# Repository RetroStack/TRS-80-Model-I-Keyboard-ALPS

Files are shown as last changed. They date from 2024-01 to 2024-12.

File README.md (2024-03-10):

# TRS-80 Model 1 - ALPS Keyboard Replica PCB

This project is a faithful reimplementation of the ALPS keyboard PCB of the iconic TRS-80 Model 1 computer. My revision, the E1, is designed to replicate the PCB design 1-to-1 of the original down to the traces. The entire project is available under the MIT license.

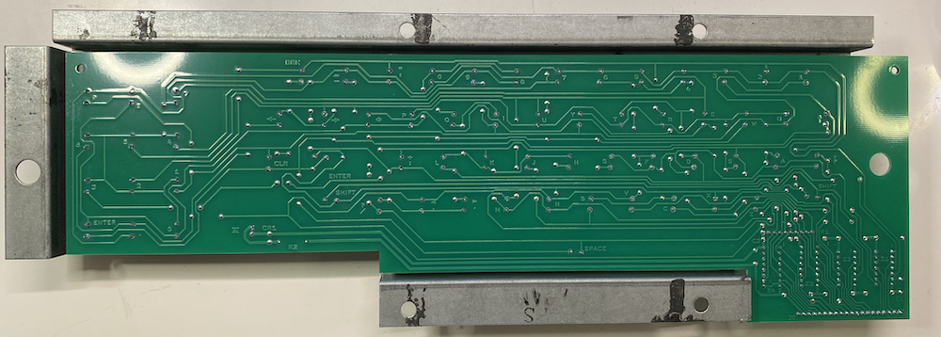
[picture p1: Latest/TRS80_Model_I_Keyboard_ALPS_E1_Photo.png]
E1 Replica


## Project Details

### Latest Files

In the "Latest" folder, you'll find the most up-to-date design files, including:

- Gerber files suitable for popular online PCB manufacturers like [PCBWay](/Latest/TRS80_Model_I_Keyboard_ALPS_E1_Gerber_PCBWay.zip) and [JLCPCB](/Latest/TRS80_Model_I_Keyboard_ALPS_E1_Gerber_JLCPCB.zip). Most manufacturers should be fine with either.
- A Bill of Materials (BOM) in [PDF](/Latest/TRS80_Model_I_Keyboard_ALPS_E1_BOM.pdf) format.
- The [full schematics](/Latest/TRS80_Model_I_Keyboard_ALPS_E1_Schematics.pdf) of the E1 replica which is 1:1 to the original G board.

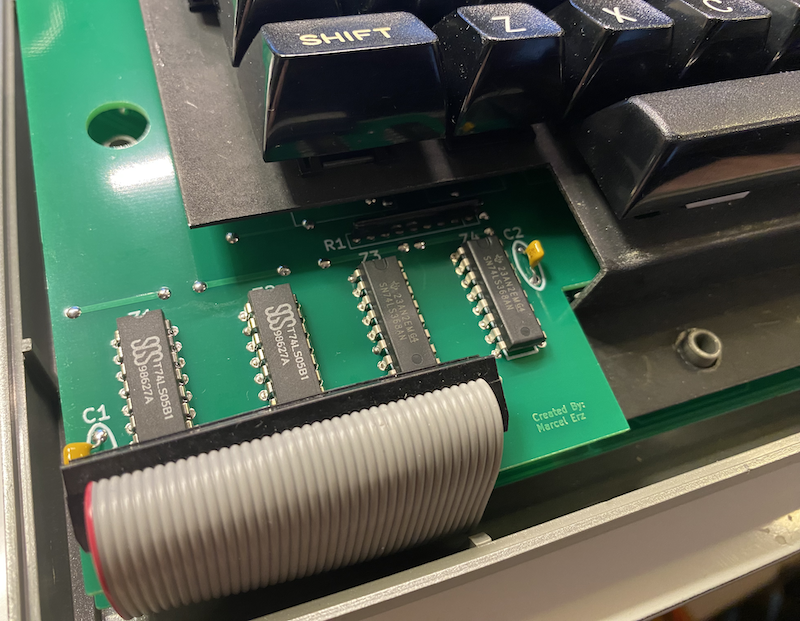
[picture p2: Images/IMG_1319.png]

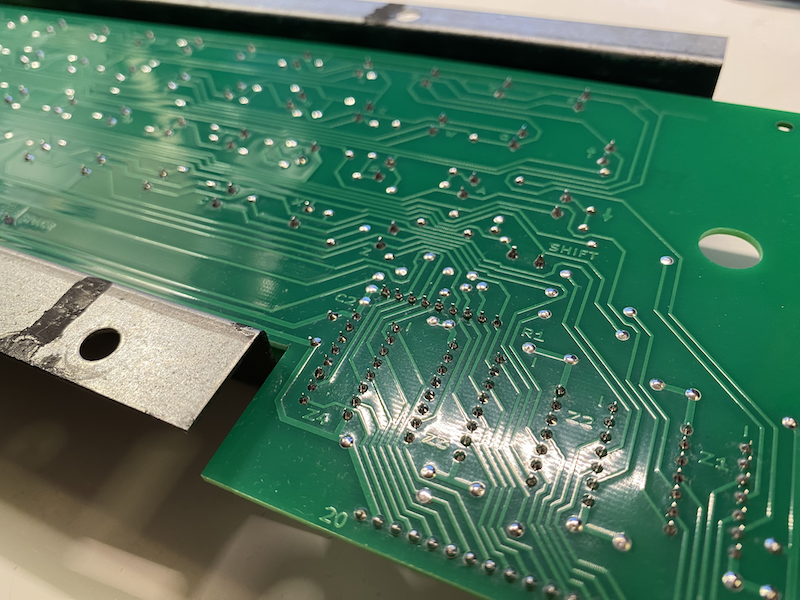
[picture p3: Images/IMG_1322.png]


### Implementation

E1 has been implemented using KiCAD 7. The KiCAD project files are included in this repository.

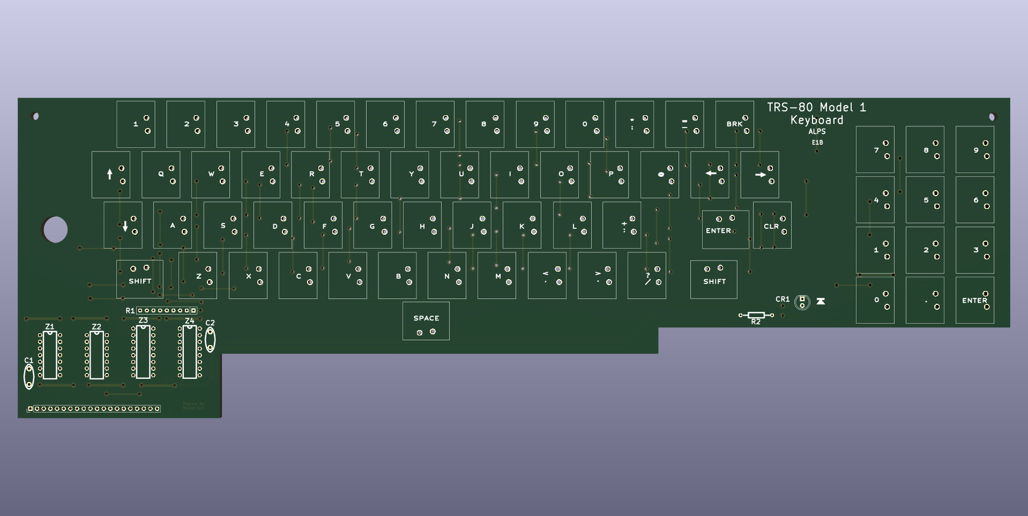
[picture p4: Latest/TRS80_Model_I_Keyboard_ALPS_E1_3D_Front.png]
E1 Replica Front

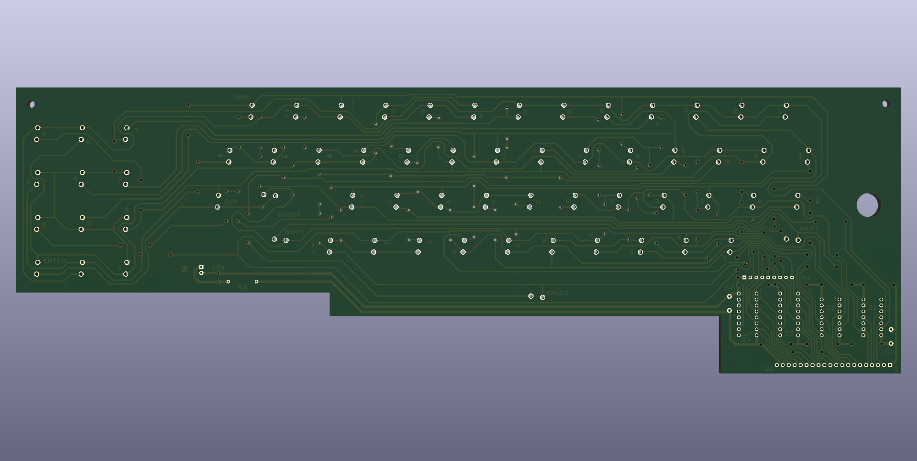
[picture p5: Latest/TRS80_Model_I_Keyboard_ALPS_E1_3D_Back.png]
E1 Replica Back


### RetroStack Libraries

To work with this KiCAD project, you'll need the RetroStack libraries for KiCAD. Please [follow this link](https://www.github.com/RetroStack/KiCAD-Libraries) to access and install these libraries.

## Main TRS-80 Model 1 Repository

For additional resources related to the TRS-80 Model 1, be sure to check out the [central page for the TRS-80 Model 1](https://www.github.com/RetroStack/TRS-80-Model-I) on [RetroStack](https://www.github.com/RetroStack).

## Support this Project

RetroStack is passionate about exploring and preserving the legacy of older computer systems. My work involves creating detailed documentation and videos to share the knowledge. I am also dedicated to reviving these classic systems by reimplementing them and offering replacement parts at no cost. If you're keen on supporting this unique project, I invite you to visit my [Patreon page](https://www.patreon.com/RetroStack). Your support would be immensely valuable and greatly appreciated!

## License

This project is licensed under the MIT License - see the [LICENSE](LICENSE) file for details.

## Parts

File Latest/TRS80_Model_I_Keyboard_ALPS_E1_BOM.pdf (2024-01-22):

### TRS-80 Model 1 ALPS Keyboard BOM

Ref | Qnty | Value | Cmp name | Footprint | Description
C1, C2 | 2 | 0.1uF | C | RetroStackLibrary:TRS80_Model_I_C_Disc_9.5L_4W_6P_Small | Unpolarized capacitor
CR1 | 1 | RED 5mm | LED | LED_THT:LED_D5.0mm | Light emitting diode
J1 | 1 | Connector | Conn_01x20 | Connector_PinHeader_2.54mm:PinHeader_1x20_P2.54mm_Vertical | Generic connector, single row, 01x20
R1 | 1 | 4.7k | R_Network08_Split | Resistor_THT:R_Array_SIP9 | 8 resistor network, star topology, bussed resistors, split
R2 | 1 | 330 | R | RetroStackLibrary:TRS80_Model_I_R_0.25W | Resistor
SW1-SW65 | 1 | @ | SW_Push | Button_Switch_Keyboard:SW_Matias_1.00u | Push button switch, generic, two pins
Z1, Z2 | 2 | 74LS05 | 74LS05 | RetroStackLibrary:TRS80_Model_I_DIP14 | Inverter Open Collect
Z3, Z4 | 2 | 74LS368 | 74LS368_Split | RetroStackLibrary:TRS80_Model_I_DIP16 | Hex buffer 3-State outputs

1

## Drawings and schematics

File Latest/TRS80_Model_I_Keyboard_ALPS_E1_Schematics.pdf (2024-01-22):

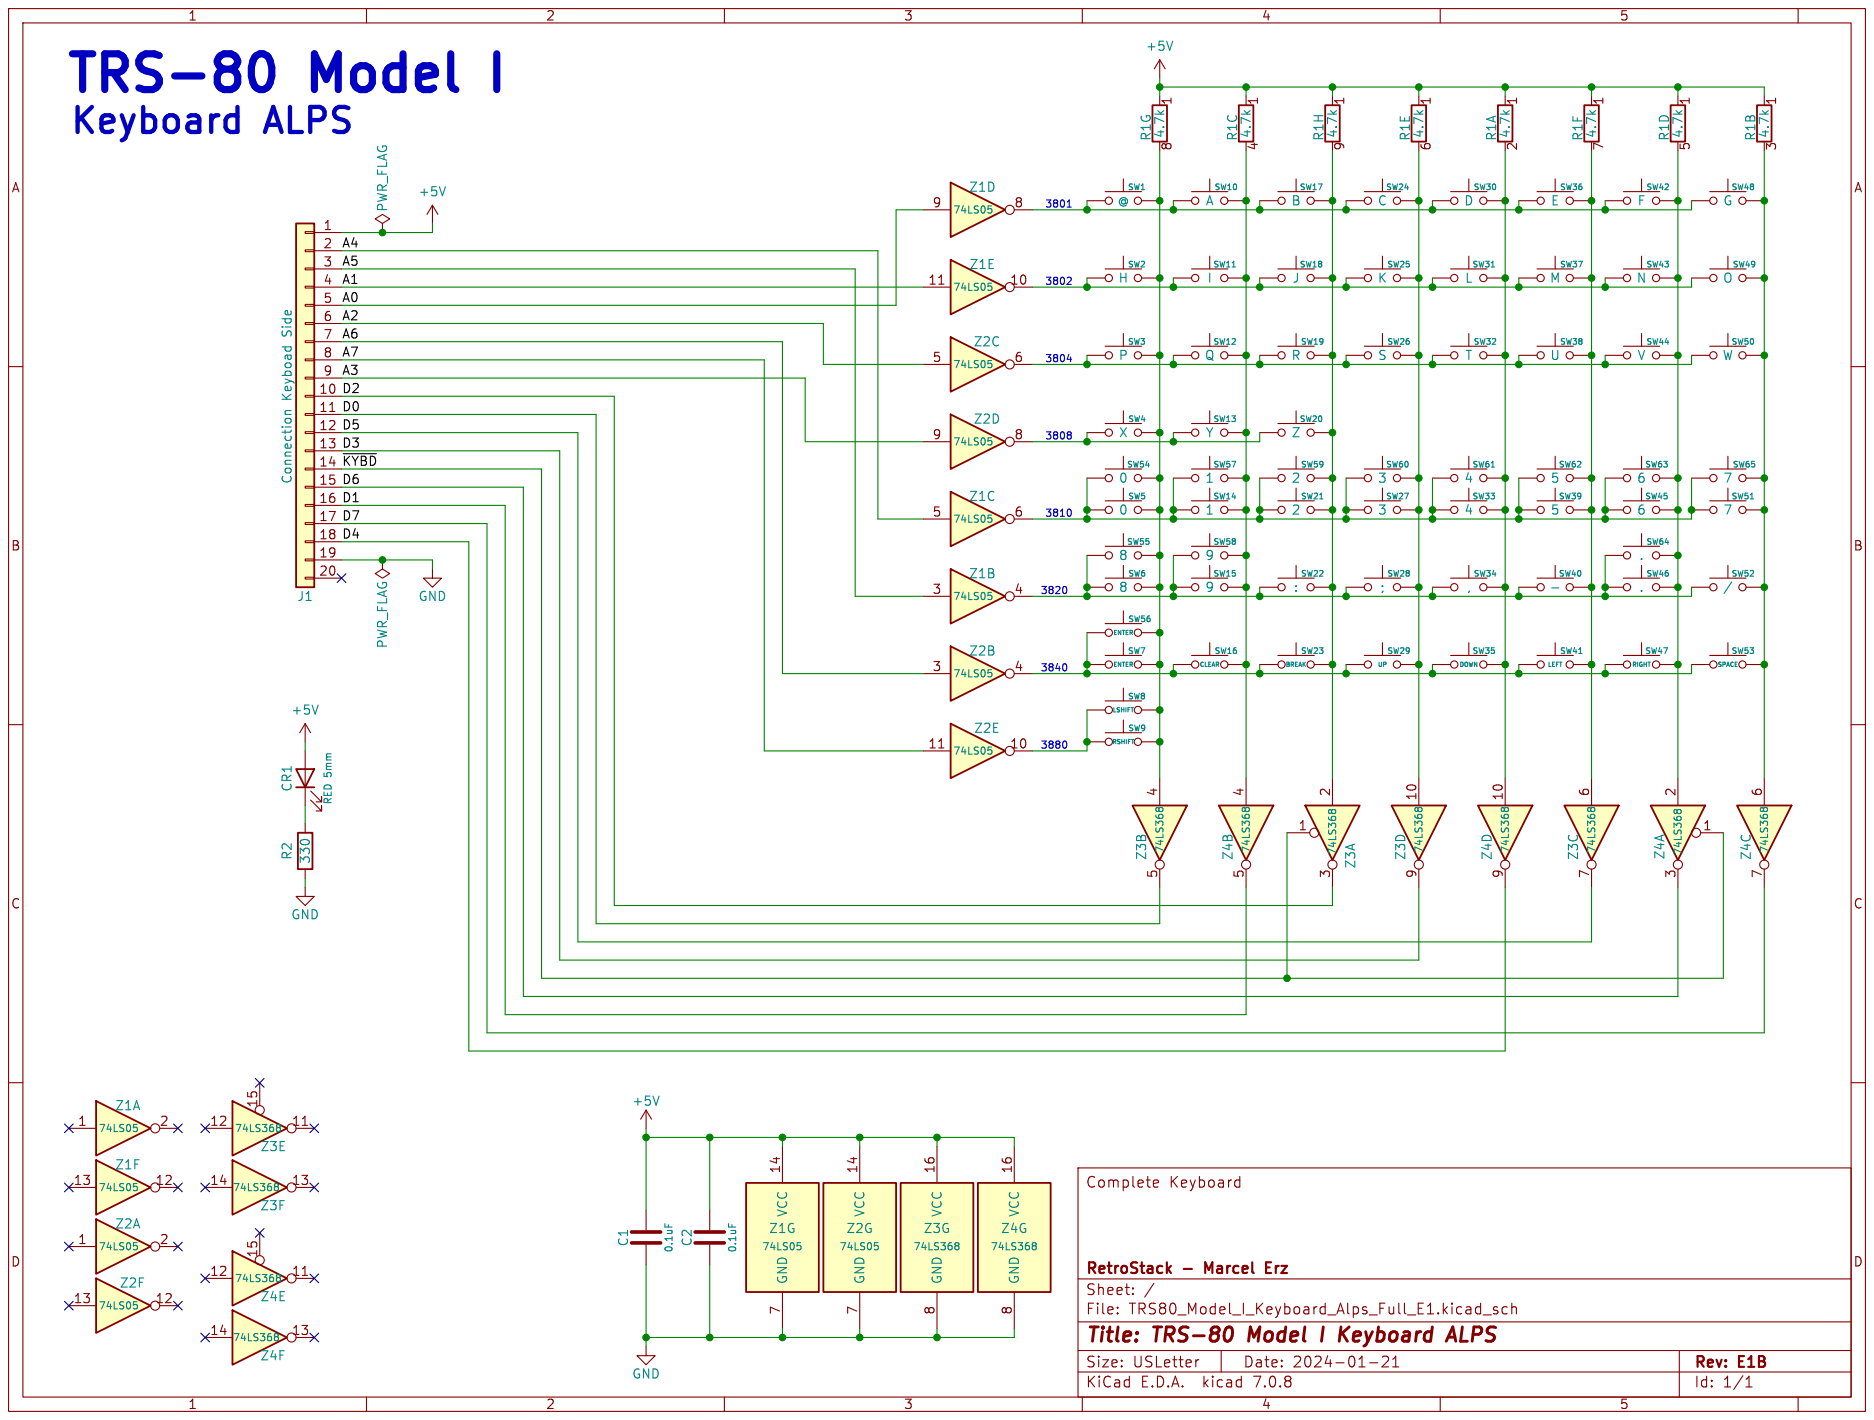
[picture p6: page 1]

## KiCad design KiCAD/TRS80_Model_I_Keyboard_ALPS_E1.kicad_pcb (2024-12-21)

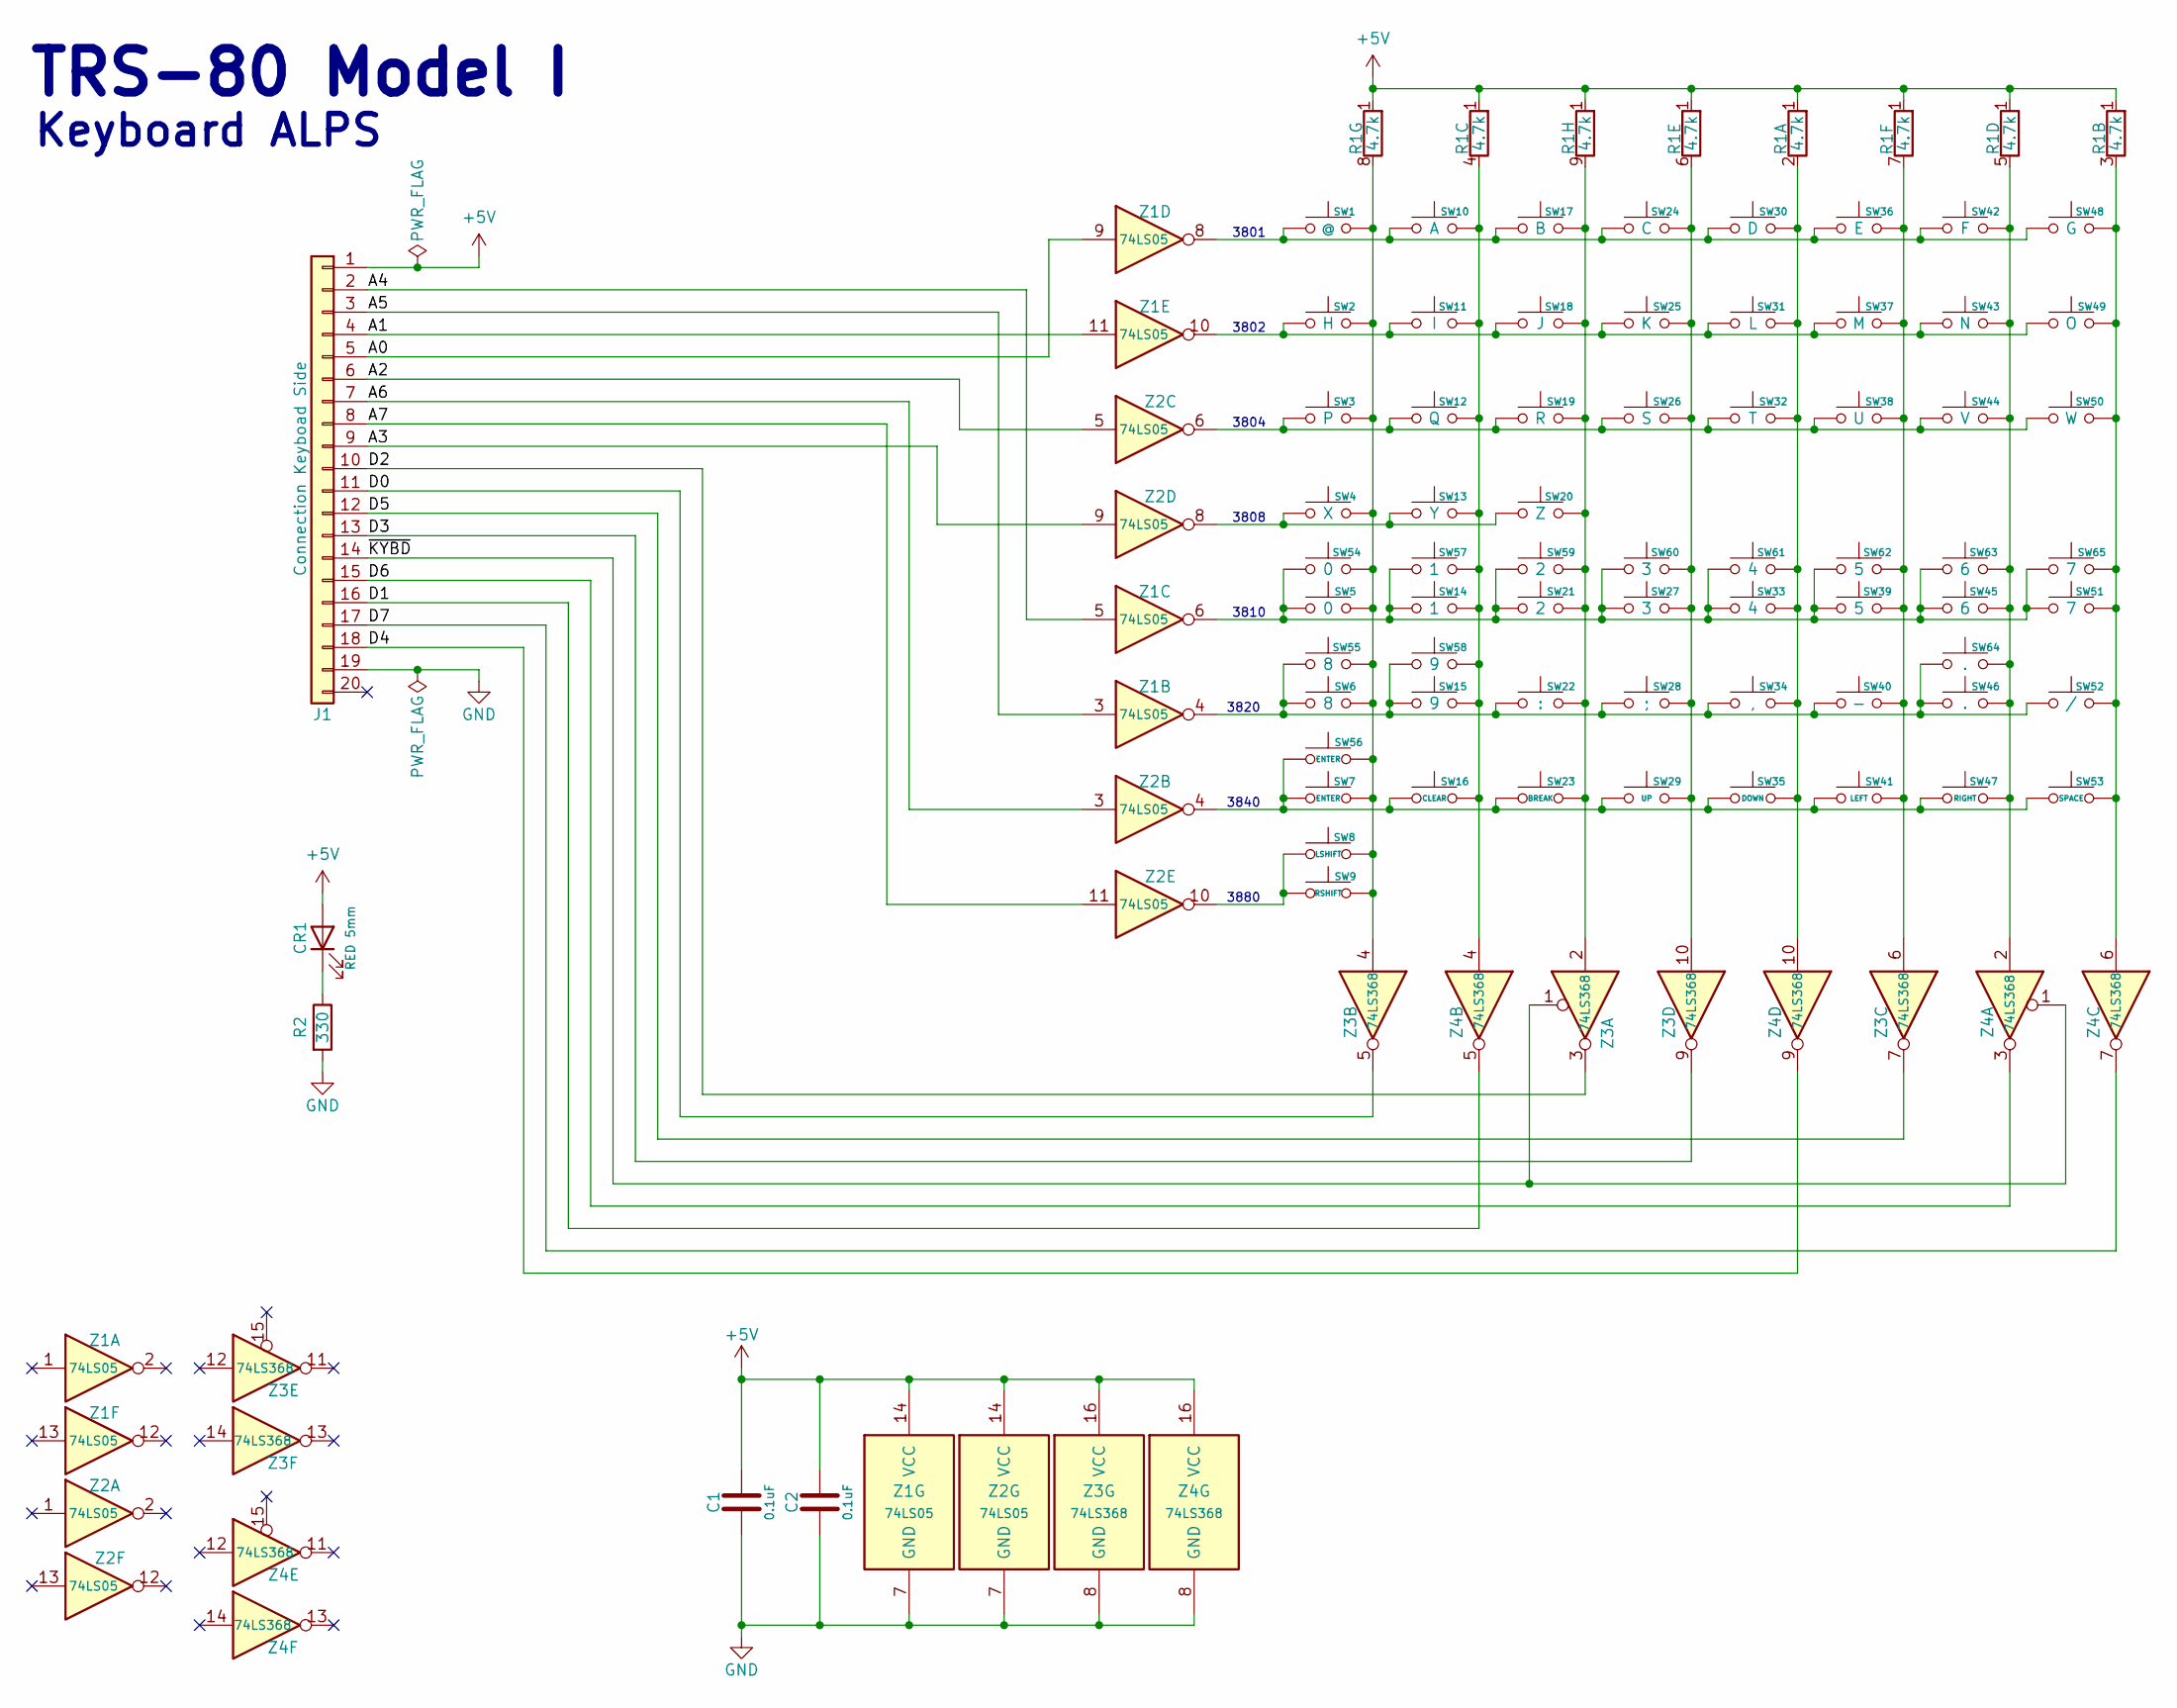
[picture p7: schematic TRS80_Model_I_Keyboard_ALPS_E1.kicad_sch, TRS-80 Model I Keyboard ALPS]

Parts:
C1, C2: 0.1uF; TRS80_Model_I_C_Disc_9.5L_4W_6P_Small
CR1: RED 5mm; LED_D5.0mm
J1: Connection Keyboad Side; PinHeader_1x20_P2.54mm_Vertical
R1: 4.7k; R_Array_SIP9
R2: 330; TRS80_Model_I_R_0.25W
SW1: @; SW_Matias_1.00u
SW2: H; SW_Matias_1.00u
SW3: P; SW_Matias_1.00u
SW4: X; SW_Matias_1.00u
SW5, SW54: 0; SW_Matias_1.00u
SW6, SW55: 8; SW_Matias_1.00u
SW7, SW56: ENTER; SW_Matias_1.00u
SW8: LSHIFT; SW_Matias_1.00u
SW9: RSHIFT; SW_Matias_1.00u
SW10: A; SW_Matias_1.00u
SW11: I; SW_Matias_1.00u
SW12: Q; SW_Matias_1.00u
SW13: Y; SW_Matias_1.00u
SW14, SW57: 1; SW_Matias_1.00u
SW15, SW58: 9; SW_Matias_1.00u
SW16: CLEAR; SW_Matias_1.00u
SW17: B; SW_Matias_1.00u
SW18: J; SW_Matias_1.00u
SW19: R; SW_Matias_1.00u
SW20: Z; SW_Matias_1.00u
SW21, SW59: 2; SW_Matias_1.00u
SW22: :; SW_Matias_1.00u
SW23: BREAK; SW_Matias_1.00u
SW24: C; SW_Matias_1.00u
SW25: K; SW_Matias_1.00u
SW26: S; SW_Matias_1.00u
SW27, SW60: 3; SW_Matias_1.00u
SW28: ;; SW_Matias_1.00u
SW29: UP; SW_Matias_1.00u
SW30: D; SW_Matias_1.00u
SW31: L; SW_Matias_1.00u
SW32: T; SW_Matias_1.00u
SW33, SW61: 4; SW_Matias_1.00u
SW34: ,; SW_Matias_1.00u
SW35: DOWN; SW_Matias_1.00u
SW36: E; SW_Matias_1.00u
SW37: M; SW_Matias_1.00u
SW38: U; SW_Matias_1.00u
SW39, SW62: 5; SW_Matias_1.00u
SW40: -; SW_Matias_1.00u
SW41: LEFT; SW_Matias_1.00u
SW42: F; SW_Matias_1.00u
SW43: N; SW_Matias_1.00u
SW44: V; SW_Matias_1.00u
SW45, SW63: 6; SW_Matias_1.00u
SW46, SW64: .; SW_Matias_1.00u
SW47: RIGHT; SW_Matias_1.00u
SW48: G; SW_Matias_1.00u
SW49: O; SW_Matias_1.00u
SW50: W; SW_Matias_1.00u
SW51, SW65: 7; SW_Matias_1.00u
SW52: /; SW_Matias_1.00u
SW53: SPACE; SW_Matias_1.00u
Z1, Z2: 74LS05; TRS80_Model_I_DIP14
Z3, Z4: 74LS368; TRS80_Model_I_DIP16

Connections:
+5V: C1.1, C2.1, CR1.2 (A), J1.1, R1.1 (R1), Z1.14 (VCC), Z2.14 (VCC), Z3.16 (VCC), Z4.16 (VCC)
/A0: J1.5, Z1.9
/A1: J1.4, Z1.11
/A2: J1.6, Z2.5
/A3: J1.9, Z2.9
/A4: J1.2, Z1.5
/A5: J1.3, Z1.3
/A6: J1.7, Z2.3
/A7: J1.8, Z2.11
/D0: J1.11, Z3.5
/D1: J1.16, Z4.5
/D2: J1.10, Z3.3
/D3: J1.13, Z3.9
/D4: J1.18, Z4.9
/D5: J1.12, Z3.7
/D6: J1.15, Z4.3
/D7: J1.17, Z4.7
/~KYBD: J1.14, Z3.1, Z4.1
GND: C1.2, C2.2, J1.19, R2.2, Z1.7 (GND), Z2.7 (GND), Z3.8 (GND), Z4.8 (GND)
unnamed: CR1.1 (K), R2.1
unnamed: R1.2 (R1.2), SW30.2, SW31.1, SW32.2, SW33.1, SW34.2, SW35.1, SW61.1, Z4.10
unnamed: R1.3 (R2.2), SW48.1, SW49.2, SW50.1, SW51.1, SW52.1, SW53.1, SW65.2, Z4.6
unnamed: R1.4 (R3.2), SW10.2, SW11.1, SW12.1, SW13.1, SW14.1, SW15.1, SW16.2, SW57.1, SW58.1, Z4.4
unnamed: R1.5 (R4.2), SW42.2, SW43.2, SW44.2, SW45.1, SW46.2, SW47.1, SW63.1, SW64.2, Z4.2
unnamed: R1.6 (R5.2), SW24.1, SW25.2, SW26.2, SW27.1, SW28.2, SW29.2, SW60.1, Z3.10
unnamed: R1.7 (R6.2), SW36.2, SW37.2, SW38.2, SW39.1, SW40.1, SW41.2, SW62.1, Z3.6
unnamed: R1.8 (R7.2), SW1.1, SW2.1, SW3.1, SW4.2, SW5.2, SW6.2, SW7.1, SW8.1, SW9.2, SW54.1, SW55.1, SW56.2, Z3.4
unnamed: R1.9 (R8.2), SW17.1, SW18.1, SW19.2, SW20.1, SW21.2, SW22.2, SW23.2, SW59.2, Z3.2
unnamed: SW1.2, SW10.1, SW17.2, SW24.2, SW30.1, SW36.1, SW42.1, SW48.2, Z1.8
unnamed: SW8.2, SW9.1, Z2.10
unnamed: SW2.2, SW11.2, SW18.2, SW25.1, SW31.2, SW37.1, SW43.1, SW49.1, Z1.10
unnamed: SW3.2, SW12.2, SW19.1, SW26.1, SW32.1, SW38.1, SW44.1, SW50.2, Z2.6
unnamed: SW4.1, SW13.2, SW20.2, Z2.8
unnamed: SW5.1, SW14.2, SW21.1, SW27.2, SW33.2, SW39.2, SW45.2, SW51.2, SW54.2, SW57.2, SW59.1, SW60.2, SW61.2, SW62.2, SW63.2, SW65.1, Z1.6
unnamed: SW6.1, SW15.2, SW22.1, SW28.1, SW34.1, SW40.2, SW46.1, SW52.2, SW55.2, SW58.2, SW64.1, Z1.4
unnamed: SW7.2, SW16.1, SW23.1, SW29.1, SW35.2, SW41.1, SW47.2, SW53.2, SW56.1, Z2.4

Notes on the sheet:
3804
3880
TRS-80 Model I
Keyboard ALPS
3808
3810
3820
3802
3801
3840

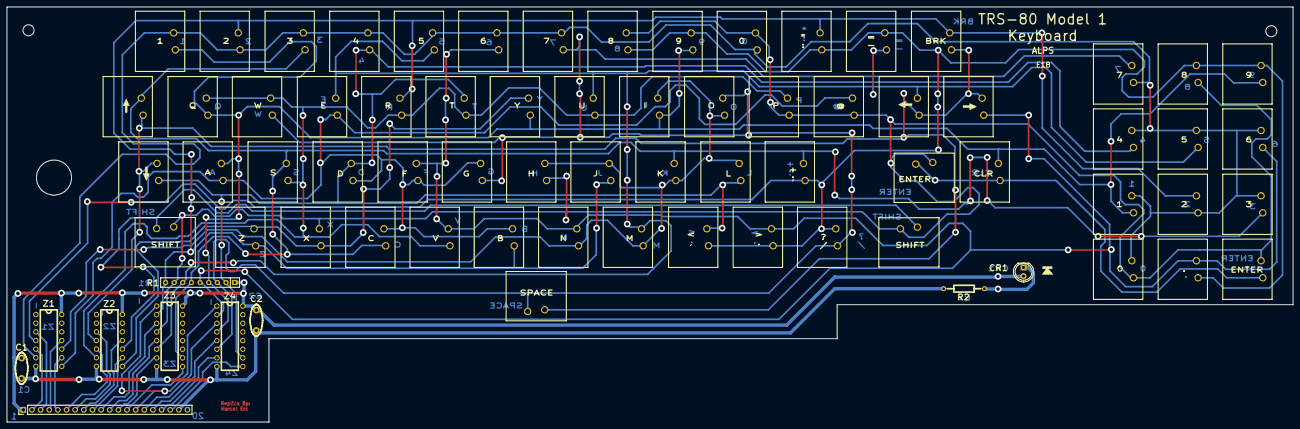
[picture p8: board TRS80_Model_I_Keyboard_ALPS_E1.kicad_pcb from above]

Board: 2 copper layers, 378.0 x 122.0 mm, 75 parts (0 on the bottom side), 36 nets.

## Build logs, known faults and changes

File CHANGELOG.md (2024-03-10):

# TRS-80 Model 1 - ALPS Keyboard Replica PCB E1 - Changelog

## Versioning

I've devised a versioning system for my replica projects. This system provides clarity about each of my version's significance. My version identifier consistently follows the original revision details, allowing for a clear distinction between the original manufacturer's revision and my own.

Here's the format for the versioning:
- The initial character is always an "E," representing my last name. This choice ensures that others can adopt the same versioning style if needed.
- The following character is a number, with "1" signifying a 1-1 re-implementation of the original. Numbers beyond "1" denote various board variations, such as new designs features, more modern components, or different interface ports.
- The final character represents my actual revision of that board. Using a character for this purpose distinguishes it from the re-implementation type mentioned above, and it allows for up to 26 revisions to refine the project.

## 13th Jan 2024 - E1A

Completed test. Fully functional.

## 21st Jan 2024 - E1B

Front silkscreen labels to help with placing keyswitches with keycaps.

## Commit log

2024-01-14 E1A initial commit
    [AddressDecoder.kicad_sch, CPU.kicad_sch, CPUGating.kicad_sch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]
2024-01-22 Cleanup & Front Silkscreen
    [AddressDecoder.kicad_sch, CPU.kicad_sch, CPUGating.kicad_sch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]
2024-12-21 General Update
    [TRS80_Model_I_Keyboard_ALPS_E1.kicad_pcb, TRS80_Model_I_Keyboard_ALPS_E1.kicad_sch]
